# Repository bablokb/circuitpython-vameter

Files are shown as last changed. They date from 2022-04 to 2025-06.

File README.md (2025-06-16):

Project circuitpython-vameter
=============================

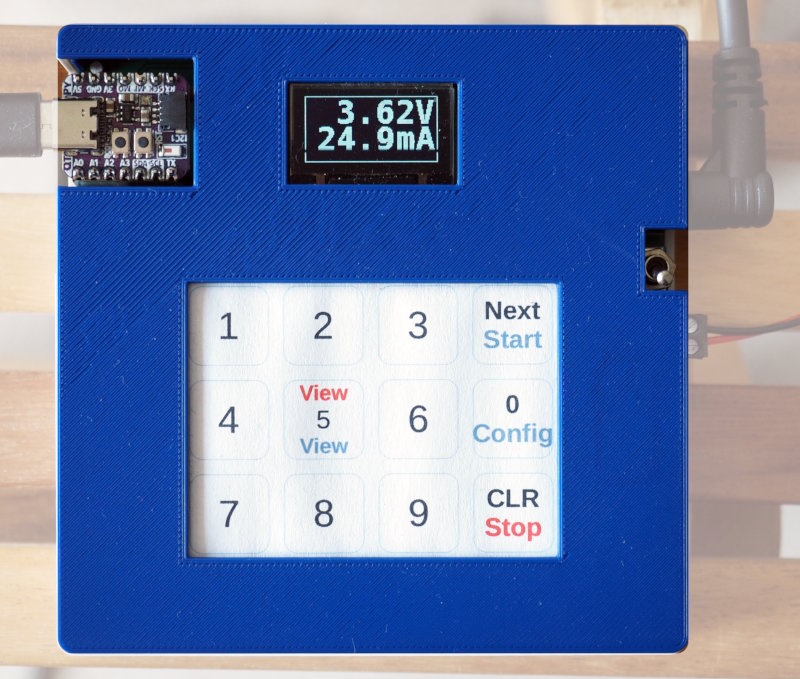
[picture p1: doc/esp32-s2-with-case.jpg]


News
----

  - 06/2025: added support for INA3221.<br>
    Changed configuration-setup (incompatible, see below)<br>
    Changed support for ESP-01S (see [ESP-01S logging HowTo](doc/esp01logger.md))
  - 02/2025: added support for recording gpio-state during sampling
  - 01/2025: added support for DataProvider-specific configuration screens
  - 02/2024: added support for logging to SD-card
  - 10/2023: added support for INA260

Overview
--------

This repository contains the necessary CircuitPyhon software to drive a
voltage/current meter based on the following components:

  - INA3221 current-sensor breakout or
  - INA219 current-sensor breakout or
  - INA260 current-sensor breakout
  - Mini OLED display with 128x64 (based on a SSD1306-chip) or
  - SPI TFT-1.8" display (based on a ST7735R-chip)
  - 4x3 touchpad (based on a MPR121-chip)

Measurements are shown on the display and written as CSV to the
console.

Note that the display and touchpad are not strictly necessary. In
this case (i.e. you only want to measure voltage/current)
you have to change configuration values directly within the source-code.

If you want to use other components (especially a bigger display or
knobs and buttons instead of the touchpad) you should read the
[hacking guide](doc/hacking.md).

Also the main program is agnostic about which kind of sensor is
sampled. Just by providing a data-provider class you can collect data of any
sensor. This is also documented in the [hacking guide](doc/hacking.md).

Hardware
--------

All components use I2C except if you choose to use the SPI-display.
Connect the respective SDA, SCL, Vcc and GND
pins with the relevant pins of the MCU. Don't forget pullups, the builtin
pullups of the MCU are usually too weak.

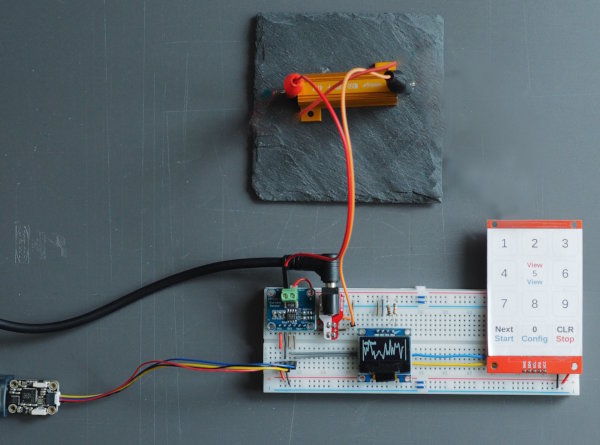
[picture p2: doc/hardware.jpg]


On the left edge: the MCU, a RP2040-Qt-Trinkey. The INA219 is left to the
barrel-jack on the upper-left side of the breadboard. On the top edge
of the image is a load-resistor. In real applications this resistor is
replaced by the load you want to measure.

The mini-oled with 128x64 pixels is in the middle, on the right is a
MPR121-based keypad with 12 keys. A template for the key-mapping is in
`doc/keypad-template.png` and `doc/keypad-template.odg`.
The latter also has a version for horizontal orientation.

The INA219-breakout has two pins (next to the I2C-interface) and a
screw-terminal for attachement of the power-source (V+) and the load (V-).
**Don't use the pins, use the screw-terminal** or else your results will
be off by about 20%.

The INA260 offers a larger measurment-range than the INA219 (up to 36V/15A
compared to 32V/2A), but is more expensive and the resolution is a
tad worse. See the relevant tutorials and datasheets for details.

The INA3221 is a three-channel chip and measures up to 26V/3.2A with a
resolution of 0.4mA.

Installation (Pico or other MCU)
--------------------------------

Steps:

  0. Install the current version of CircuitPython to your device

  1. Install the following libraries from the CircuitPython library-bundle to
     the `lib`-directory of your device  

       - adafruit_bitmap_font
       - adafruit_bus_device
       - adafruit_connection_manager
       - adafruit_display_shapes
       - adafruit_display_text
       - adafruit_displayio_ssd1306
       - adafruit_ina219
       - adafruit_ina260
       - adafruit_ina3221
       - adafruit_mpr121
       - adafruit_register
       - adafruit_requests
       - adafruit_st7735r
       - adafruit_ticks
       - asyncio

     The preferred way to do this is to use `circup` (note that the device
     must be mounted):  

         sudo apt-get -y install pip3
         sudo pip3 install circup
         circup --path /mountpoint/of/device install -r requirements.txt

  2. Clone the repository

  3. Configure the software for your board and preferences. See
     [Configuration](#configuration) below.

  4. Check `src/lib/INA219DataProvider.py` for the correct voltage range.
     The code uses the library-default of 32V/2A, but this can be changed
     to 16V/1A or 16V/400mA. The additional precision is probably not
     worth the effort. Also, you can change the chip-internal oversampling
     of the ADC. The Default uses 8x oversampling resulting in a minimal
     sampling time of 4.26ms. Defaults for the INA260 are in
     `src/lib/INA260DataProvider.py`

  5. Copy all files from below `src` to your device.

Installation (Raspberry Pi)
---------------------------

There is a native build of CircuitPython for the Raspberry Pi, but that
build is extremely slow and not usable yet. The better option is to
use _Blinka_, an emulation layer which provides classes and methods usually
missing in a native python installation. Blinka runs on various SBCs,
the Raspberry Pi is only the most prominent example.

You can install the project on a Raspberry Pi (or any other Debian-based SBC
with Blinka-support) using:

    sudo tools/install-pi

This installs the project files, Blinka and all necessary libraries to
`/usr/local/cp-vameter`. To run the program, just use the command
`cp-vameter`. This assumes that `/usr/local/bin` is within your path.

Note that the installation is quite slow, because the install-command
installs everything to a python-virtenv. Especially download, compile
and install of numpy takes a lot of time, even on the faster Pis. For
running the program, a Pi-Zero is more than sufficient.

Also note that Blinka currently only supports SPI-displays with 16-bit
colors.

Configuration
-------------

Configuration is done using variables from three different files:

  - `src/<board_id>/board_config.py`: board-specific pins
  - `src/def_config.py`: default values
  - `src/user_config.py`: user-specific overrides

A board-specific configuration file is usually not necessary. There
are some seldom cases where the board uses different names for some
pins (e.g. `board.SCLK` instead of `board.SCK`). In this case a
board-specifc file is necessary. Other cases could be boards with
hard-wired displays/SD-slots that use specific pins for these
peripherals.

This repository has support-files for a number of platforms. If you use
a different MCU and that MCU does not provide the default pins, you should
create a directory `src/<board_id>` with a file `board_config.py`. Please
also create a pull-request in this case. `<board_id>` is the value
of `board.board_id` which you can query in the REPL after importing
the board-module.

The user-specific configuration file `src/user_config.py` is not part
of the repository. Copy `src/def_config.py` and keep only variables
you actually change.

**Note: starting with version 04/2025, the format of the configuration
file has changed.** Be sure to update any exiting user-specific
configuration files to match the format of `src/def_config.py`.

Usage
-----

The program is in three modes: _ready_ (after power-on and reset),
_active_ and _config_. Possible transitions are _ready-active-ready_ and
_ready-config-ready_.

If no keypad is detected, the program runs exactly once using the
defaults defined in the configuration files.

To switch modes, use the keypad:

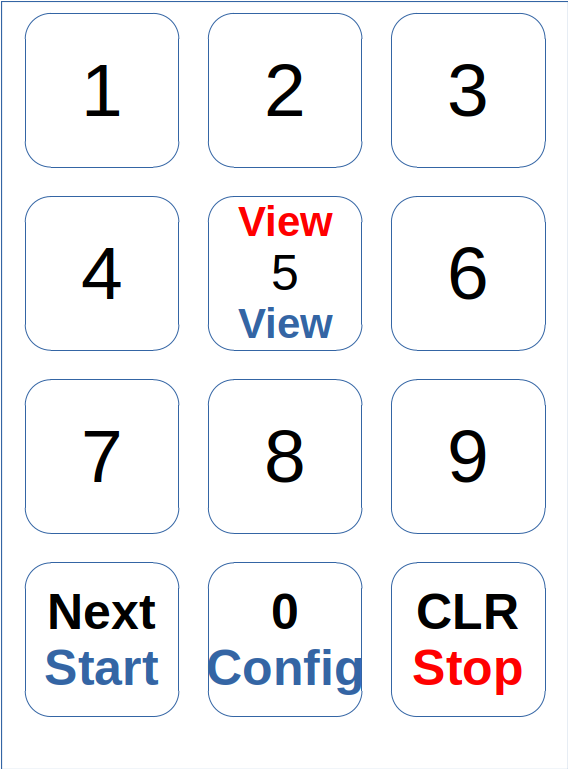
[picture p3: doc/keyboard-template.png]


Keys in blue are valid for the ready-mode, keys in black during configuration
and keys in red during the active-mode.

If you run the program on a SBC using the Blinka-emulation, you can
also provide settings via commandline parameters. For a list of options
run

    cp-vameter -h

This is especially useful for headless operation, i.e. without display
and without keypad.

Ready-Mode
----------

The ready-mode displays the last measurement-results (switch by using the
"View"-button):

 

Use the "Start" or "Config"-buttons to start a measurement or to enter
configuration mode.

Config-Mode
-----------

Once the program is in configuration mode, you can enter various parameters:

  - **Int-Scale**: the scale of the sampling interval in ms/s/m/h/d  
    The values 1-5 on the keypad are mapped to these intervals
  - **Interval**: the sampling interval in the given scale  
    
  - **Duration**: the duration of the measurement. A value of zero
    will run the measurement until it is explicitly or implicitly stopped.
    The scale of the duration depends on the scale of the interval. E.g. a
    interval-scale of 'ms' (i.e. in milliseconds) will force a duration
    measured in seconds. For an interval-scale of 's' the duration-scale will
    be in minutes and so on.  
    
  - **Update**: update-interval of the screen in milliseconds. These updates
    slow down the sampling, so make sure this value is much larger than the
    value of `interval`. Setting the value to zero will disable
    updates of the display during measurement.  
    
  - **DataProvider specific Configuration**: additional configurations for
    the DataProvider in use.

The "Next"-button will navigate through the configuration screens, after the
last item the system switches back to ready-mode.

DataProvider specific configuration is available for:

  - [`INA219Dataprovider`](./doc/ina219-config.md)
  - [`INA260Dataprovider`](./doc/ina260-config.md)

Active-Mode
-----------

During active-mode the program continuously reads the sensor and collects
and displays data. Actual sampling starts as soon as the voltage and
current is above a default threshold (1V/0.5mA) and stops again once

  - the values drop again below these limits, or
  - the configured measurement duration is reached or
  - you press the "Stop"-button

Using the "View"-button you cycle through various views:

  - voltage and current  
    
  - elapsed time  
    
  - plot-view of voltage  
    
  - plot-view of current  
    

Recording State during Sampling
-------------------------------

To record application state during sampling, you need extra pins
that the application sets to high or low depending on the state. These
pins have to be connected to the driving MUC and should be operated in
push-pull mode by the device under test.

In addition, you need to set e.g.

    PINS_APP = [(board.GPx,1), (board.GPy,0)]

in your `src/user_config.py`. `board.GPx` and `board.GPy` are gpios of
the MCU running circuitpython-vameter, not the gpios of the device under
test.

The example uses one state-pins that is active high and a second that is
active low.

Tips and Tricks
---------------

The default configuration of the sensor uses 8x oversampling for the
internal ADC. This reduces noise. Sampling-time according to the
datasheet is 4.26ms. Using less oversampling or less precision you
can bring this down to below 1ms, but if you really need high-frequency
sampling in this range you should think about reimplementing the project
using an optimzed setup and probably C/C++.

Using a Pico, you can reach a minimal sampling interval of about 9.5ms
(about 5.4ms measured on a Pi3B+, about 6.6ms on a QT Py ESP32-S2).

Display-updates take about 330ms. During update, you loose all samples.
*Setting the update-interval to zero prevents data-loss*, but you
can't see the values during measurement. When the
sampling-interval is larger than 330ms, no data-loss occurs regardless
of display-updates.

During active measurement, the default setup not only displays the
values, but also plots of the data. This is also costly (in speed
and memory) and can be disabled in `src/user_config.py` with the constant
`DEF_PLOTS`.

Note that the plots _don't_ show all measured values, but only the values
during display-updates. I.e. the plots just show the values from the
normal value-view across time. If you sample at 100ms and the display
update is every second, you will see every tenth value.

For ex-post data-visualization, save the data from the serial output
to a file and then use the
[Python Datamonitor](https://github.com/bablokb/py-datamon) to create
a plot. A ready to use configuration-file is in
[doc/cp-vameter.json](./cp-vameter.json).

The INA219 provides voltage, current and power. The default configuration
does not sample power. If you need all three values, you can change
this within `lib/INA219DataProvider` (set `WITH_POWER=True`).

In this file you can also change some additional settings, e.g. sample
frequency and voltage/current range as well as the cutoff-values used
for detecting start and stop of measurements.

Logging via WLAN is possible either with native WIFI (for those boards
with builtin WIFI) or an additional ESP-01S MCU connected to the UART
of the device. For details, read the [ESP-01S logging
HowTo](doc/esp01logger.md).

If the program runs on an device with native WIFI you can use the
builtin wifi for data-logging. See [UDP logging
HowTo](doc/udplogger.md) for details.

You can also log to a file on a SD-card. Add the following line to
your `user_config.py`:

    from SDCardLogger import DataLogger

This is useful for autonomous long-term logging, e.g. when charging a
battery. Tested with a Qt-Py-RP2040 with SD-card BFF. Fastest logging
interval was 7ms.

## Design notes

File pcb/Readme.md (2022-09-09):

A PCB for the INA219 and INA260
===============================

In this directory you will find the KiCAD-files for a 10x10cm pcb
for the INA219 and the INA260. The latter is untested, since it
is currently not available. The pcb is symetrical, i.e. you either
add components for the INA219 (top-left, top and middle right) or
for the INA260.

The connectors on the top and bottom are for the OLED and the keypad.
Alternatively, you could add Grove-connectors.
You also have to solder the two pullup-resistors in the middle.

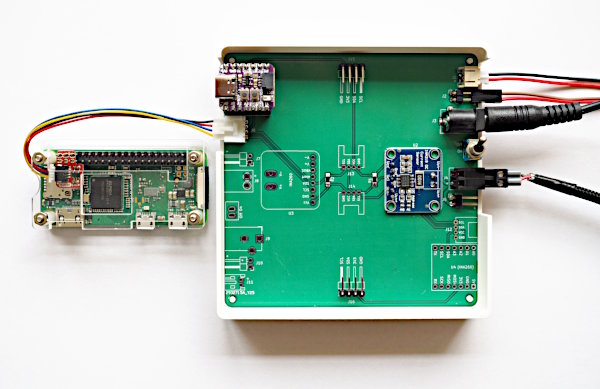
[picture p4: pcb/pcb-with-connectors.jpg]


The image shows a pcb with INA219. On the left you _either_ connect
a suitable mcu (see below) on the top-left, _or_ you connect an external
mcu (or Pi) using an I2C-Grove-connector. In the image you can see
both options.

On the right side, you have three power inputs for the load (use only one):

  - a JST-PH2 connector for LiPos
  - DuPont jumper pins
  - a 5.5/2.1mm barrel jack

Below the power switch are two power connectors (connect one of them to
to the load):

  - an AKL-182 socket
  - DuPont jumper pins

The AKL-182 socket takes AKL-169 plugs. I use these with various adapter
wires, equiped e.g. with micro-USB, USB-C, JST-PH2 on the other end.

As an alternative, you could use plain 3.5mm screw-terminals.

The pcb was ordered using JLCPCB.

OpenSCAD-files for the case are available in the toplevel `3D`-directory.

Supported MCUs
--------------

The driving MCU can be added to the board if it uses the XIAO-standard.
Possible alternatives:

  - Adafruit QT Py RP2400
  - Adafruit QT Py ESP32-S2
  - Seeedstudio XIAO RP2400

The form-factor alone is not sufficient, the MCU must also have enough
RAM/flash to support the application.

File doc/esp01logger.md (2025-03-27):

Howto use the ESP01Datalogger
=============================

Support for the ESP-01S has been dropped. The code used the library
`adafruit_espat` which is no longer supported.

Nevertheless, logging with WIFI using an ESP-01S still works. To use
it, you need to install the library
[circuitpython-esp32at](https://github.com/bablokb/circuit-python-esp32at). Once
installed, initialize the wifi-coprocessor in your `user_config.py`. After
initialization, use the standard [UDPLogger](./udplogger.md) for
logging.

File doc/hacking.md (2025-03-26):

Porting to other hardware
=========================

Since CircuitPython runs on a wide array of platforms, this is not so
much about porting the code to something totally different, but to adapt
it for other hardware components.

This document gives an overview over the application classes to help
changing the code for other hardware. All files are relative to `src`, after
installation relative to the root of the device.

main.py
-------

The main application-file. It imports classes for specific features.
When implementing new versions for features (e.g. data-provider, logging),
keep the class name and change the import statement. The files
`lib/FakeDataProvider.py` vs. `lib/INA219DataProvider.py` are an example:
both files define the class `DataProvider`.

lib/View.py
-----------

This file defines all the views for the application. To adapt to larger
displays, add colors and so on you have to provide your own implementation.

The small 128x64 display is fine for up to three rows of data. The plot-view
is already more of a gimmick. Better, but still afordable are
160x128 TFT-displays (attached to SPI). The current support of this
display is minimal, the code only uses the central 128x64 pixels and
ignores the availability of colors.

The fonts in the `fonts`-directory are stripped down versions of the
original fonts. If you need additional characters, follow the instructions
in [fonts.md](./fonts.md).

lib/Touchpad.py
---------------

This file implements the class `KeyEventProvider`. For other hardware like
buttons and rotary-encoders, implement a class with identical methods.

An interessting platform would be the PyPortal-line. It has an integrated
processor and with the touch-display you could implement an onscreen
touchpad.

lib/INA219DataProvider.py
-------------------------

The file implements the class `DataProvider`. You could swap the dataprovider
with something simlar (e.g. INA260) or totally different. A BME280 sensor with
temperature, pressure and humidity would be a candidate.

An alternative implementation which is part of the project is the
`FakeDataProvider.py`. It is useful during development and testing since it
neither needs a real current-sensor, nor an existing load.

Other sensors would certainly need other characters within the font-set,
so you must also update the fonts.

If the data-provider is not targeted at sampling in the milliseconds realm,
you should also change the constant `DEF_TM_SCALE` to `s` instead of `ms` in
`src/user_config.py`.

lib/SerialLogger.py
-------------------

Implements the class `DataLogger` (logging to the serial console).
Alternative implementations must implement at least the `log()`-method.

lib/UDPLogger.py
------------------

Implements the class `DataLogger` (logging via WLAN). For details, read
the [UDP logging HowTo](./udplogger.md).

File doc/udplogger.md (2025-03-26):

Howto use the UDPLogger
=======================

Overview
--------

This class allows data-logging via WLAN on devices with native WIFI.
This is not for devices that have an ESP32 as a coprocessor, e.g. a
PyPortal!

UDP works even if no remote host is listening and thus more robust
than TCP. The setup time (connection to AP) is quite long, but the
overhead during logging is only about 1ms.

To receive the data, run something like

    netcat -u l 6500

on a machine in the network and pass the ip and port of the machine in
the file `secrets.py` (see below).

As an alternative, run

    tools/cp-datalogger.py -t -o mydata.csv

The complete list of options for `cp-datalogger.py` are available via

    tools/cp-datalogger.py -h

Configuration
-------------

Add

    from UDPLogger import DataLogger

to your `user_config.py`.

secrets.py
----------

Create the file `secrets.py` with the following content:

    secrets = {
      'ssid' :        'ssid-of-accesss-point',
      'password' :    'PSK-2 shared key',
      'retry':        number-of-retries,
      'remote_ip':    'IP of remote host receiving the logs',
      'remote_port' : port-number
    }

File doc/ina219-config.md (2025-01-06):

Specific Configuration for the INA219
=====================================

The INA219 dataprovider allows the configuration of the measurement range
and the ADC-oversampling.

Measurement Range
-----------------

Available configuration options (default value: **1**):

  - **2**: 32V, 2A with 0.49mA resolution
  - **1**: 32V, 1A with 0.25mA resolution
  - **400**: 16V, 400mA with 0.01mA resolution

ADC Oversampling
----------------

Oversampling is related to noise and conversion time. A higher oversampling
will result in less noise but with a higher conversion time.

Available configuration options (default value: **6**):

  - **0**:   9 bit,    1 sample,     84us
  - **1**:  10 bit,    1 sample,    148us
  - **2**:  11 bit,    1 sample,    276us
  - **3**:  12 bit,    1 sample,    532us
  - **4**:  12 bit,    2 samples,  1.06ms
  - **5**:  12 bit,    4 samples,  2.13ms
  - **6**:  12 bit,    8 samples,  4.26ms
  - **7**:  12 bit,   16 samples,  8.51ms
  - **8**:  12 bit,   32 samples, 17.02ms
  - **9**:  12 bit,   64 samples, 34.05ms
  - **10**: 12 bit,  128 samples, 68.10ms

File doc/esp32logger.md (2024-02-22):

Howto use the ESP32Datalogger
=============================

Overview
--------

This class allows data-logging via WLAN on devices with the ESP32-chip
(e.g. Qt Py ESP32-S2 from Adafruit). This is not for devices that
have an ESP32 as a coprocessor, e.g. a PyPortal!

Compared to the ESP-01, the setup time (connection to AP) is quite long,
but the overhead during logging is only about 1ms.

To receive the data, run something like

    netcat -u l 6500

on a machine in the network and pass the ip and port of the machine in
the file `secrets.py` (see below).

As an alternative, run

    tools/cp-datalogger.py -t -o mydata.csv

The complete list of options for `cp-datalogger.py` are available via

    tools/cp-datalogger.py -h

Configuration
-------------

Add

    from ESP32DataLogger import DataLogger

to your `user_config.py`.

secrets.py
----------

Create the file `secrets.py` with the following content:

    secrets = {
      'ssid' :        'ssid-of-accesss-point',
      'password' :    'PSK-2 shared key',
      'transport':    'UDP or TCP',
      'retry':        number-of-retries,
      'remote_ip':    'IP of remote host receiving the logs',
      'remote_port' : port-number
    }

UDP works even if no remote host is listening and is a bit faster.

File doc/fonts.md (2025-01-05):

Fonts
=====

The program uses the *DejaVuSansMono-Bold* font in two different
font-sizes. The tiny-font is the default builtin font `terminalio.FONT`. If
you prefer a different tiny-font, change the definition within
'src/lib/View.py`.

To keep the size small, only the subset of characters actually used
are within the fonts. These subsets were created following the
tutorial from
<https://learn.adafruit.com/custom-fonts-for-pyportal-circuitpython-display>.

Conversion to PCF was done using the online converter from
<https://adafruit.github.io/web-bdftopcf/>.

Text strings
------------

The program uses the following text strings:

  - Int-Scale:
  - Interval:
  - Oversample:
  - Duration:
  - Update:
  - min:
  - mean:
  - max:
  - Calibration:
  - ADC-Overs.:
  - AVG-Count:
  - Conv-Time:

Values and Units
----------------

Characters needed for values and units:

  - numbers
  - V
  - mA
  - mW
  - ms, s, m, h, d

Character table
---------------

Note that the tiny-version if the font currently contains all characters
unless you change the definition. In this case ensure that all characters
from the table are contained in the font.

| Char | Tiny | Small | Large |
|---|---|---|---|
| sp | X  | X | X |
| . | X  | X | X |
| - | | X | X |
| 0 | X  | X | X |
| 1 | X  | X | X |
| 2 | X  | X | X |
| 3 | X  | X | X |
| 4 | X  | X | X |
| 5 | X  | X | X |
| 6 | X  | X | X |
| 7 | X  | X | X |
| 8 | X  | X | X |
| 9 | X  | X | X |
| : | X  | X | X |
| A | X  | X | X |
| C | | X | |
| D | | X | |
| G | | X | |
| I | | X | |
| M | X  | X | X |
| O | | X | |
| S | | X | |
| U | | X | |
| V | X  | X | X |
| W | X  | X | |
| a | | X | |
| b | | X | |
| c | | X | |
| d | | X | X |
| e | | X | |
| h | | X | X |
| i | | X | |
| l | | X | |
| m | X  | X | X |
| n | | X | |
| o | | X | |
| p | | X | |
| r | | X | |
| s | X  | X | X |
| t | | X | |
| u | | X | |
| v | | X | |
| x | | X | |
|------|------|-------|-------|

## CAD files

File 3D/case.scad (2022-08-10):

// -----------------------------------------------------------------------------
// 3D-Model (OpenSCAD) case (bottom) for INA219-pcb.
//
// Author: Bernhard Bablok
// License: GPL3
//
// ---------------------------------------------------------------------------

include <dimensions.scad>
include <BOSL2/std.scad>


// --- pcb-support   ---------------------------------------------------------

module pcb_support() {
  h = z_sup;
  d = 2*r_pcb;
  z = b-fuzz;
  move([r_pcb+w4+gap,r_pcb+w4+gap,z]) cyl(h=h,d=d,anchor=BOTTOM+CENTER);
  move([r_pcb+w4+gap,y_pcb-r_pcb+w4,z]) cyl(h=h,d=d,anchor=BOTTOM+CENTER);
  move([x_pcb-r_pcb+w4,r_pcb+w4+gap,z]) cyl(h=h,d=d,anchor=BOTTOM+CENTER);
  move([x_pcb-r_pcb+w4,y_pcb-r_pcb+w4,z]) cyl(h=h,d=d,anchor=BOTTOM+CENTER);
}


// --- pcb-holder (fits to mounting holes)   ---------------------------------

module pcb_holder() {
  h = 2*z_pcb;
  d = d_sup - gap;
  z = b + z_sup-2*fuzz;
  move([r_pcb+w4+gap,r_pcb+w4+gap,z]) cyl(h=h,d=d,anchor=BOTTOM+CENTER);
  move([r_pcb+w4+gap,y_pcb-r_pcb+w4,z]) cyl(h=h,d=d,anchor=BOTTOM+CENTER);
  move([x_pcb-r_pcb+w4,r_pcb+w4+gap,z]) cyl(h=h,d=d,anchor=BOTTOM+CENTER);
  move([x_pcb-r_pcb+w4,y_pcb-r_pcb+w4,z]) cyl(h=h,d=d,anchor=BOTTOM+CENTER);
}

// --- connector for cover-snap   --------------------------------------------

module snap_male(orient) {
  prismoid(size1=[2*snap_h,snap_w], size2=[0,snap_w-2*snap_h], 
           h=snap_h, orient=orient, anchor=FRONT+RIGHT+BOTTOM
  );
}


// --- case (bottom-part)   --------------------------------------------------

module case() {
  z = b + z_sup + z_pcb + zsize;
  difference() {
    cuboid(                                          // outer
      [xsize+2*w4,ysize+2*w4,z], rounding=r_pcb,
      edges="Z",
      anchor=FRONT+LEFT+BOTTOM
    );
    cuboid(                                          // minus inner
      [xsize,ysize,z], rounding=r_pcb,
      edges="Z", p1=[w4,w4,b],
      anchor=FRONT+LEFT+BOTTOM
    );

    cuboid([x_mcu_grove,w4+2*fuzz,z],
      p1=[w4+gap+x_mcu_off,0,b+z_sup+z_pcb]);               // cutout mcu/grove
    cuboid([x_conn,w4+2*fuzz,z],
      p1=[w4+gap+x_conn_off,ysize+w4-fuzz,b+z_sup+z_pcb]);  // cutout connectors
  }

  pcb_support();
  pcb_holder();
}

// --- top-level object   ----------------------------------------------------

case();

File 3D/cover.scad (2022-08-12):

// -----------------------------------------------------------------------------
// 3D-Model (OpenSCAD) cover (top) for INA219-pcb.
//
// Author: Bernhard Bablok
// License: GPL3
//
// -----------------------------------------------------------------------------

include <dimensions.scad>
include <mpr121-keypad.scad>
include <oled-128x64.scad>

include <BOSL2/std.scad>


x      = xsize+2*w4;
y      = ysize+2*w4;
xr_mcu = w4+gap+x_mcu_off+x_mcu;         // right border of x_mcu

y_kp = (y-yi_kp)/2 -                     // (total size - cutout keypad size)/2 minus
       (yo_kp - yi_kp - yi_kp_off);      // lower offset of cutout keypad

module cover() {
  difference() {
    cuboid(
        [x,y,b], rounding=3,
        edges="Z", p1=[0,0,0],
        anchor=FRONT+LEFT+BOTTOM
    );
    cuboid([x_mcu,y_mcu,b+2*fuzz],p1=[w4+gap+x_mcu_off,-fuzz,-fuzz]);      // cutout for mcu
    cuboid([x_sw,y_sw,b+2*fuzz],p1=[w4+gap+x_sw_off,y-y_sw+fuzz,-fuzz]);   // cutout for switch
    cuboid([y_oled,x_oled,b+2*fuzz],p1=[w4+gap+x_mcu_off,
                                      (y-x_oled)/2,-fuzz]);                // empty space for oled
    cuboid([xo_kp,yo_kp,b+2*fuzz],p1=[xr_mcu + (x-xr_mcu-xo_kp)/2,
                                      y_kp,-fuzz]);                        // empty space for keypad
    }
  // add oled
  move([y_oled+w4+gap+x_mcu_off,(y-x_oled)/2,b]) zrot(90) zflip() oled();

  // add keypad
  move([xr_mcu + (x-xr_mcu-xo_kp)/2,y_kp,b]) mirror([0,0,1]) yflip(y=yo_kp/2) keypad_frame();
}

module wall() {
  z = zsize - 1;
  difference() {
    cuboid([xsize-gap,ysize-gap,z], rounding=3, edges="Z",
           anchor=FRONT+LEFT+TOP,p1=[w4+gap/2,w4+gap/2,-z]);
    cuboid([xsize-gap-2*w2,ysize-gap-2*w2,z+2*fuzz], rounding=3, edges="Z",
            anchor=FRONT+LEFT+TOP,p1=[w4+gap/2+w2,w4+gap/2+w2,-z]);
    cuboid([x_mcu_grove,w4+w2+gap+fuzz,b+z+2*fuzz],
            anchor=TOP+CENTER,
            p1=[w4+gap+x_mcu_off,-fuzz,-z-b]);         // cutout for mcu+grove
    cuboid([x_conn,w4+w2+gap+fuzz,b+z+2*fuzz],
            anchor=TOP+CENTER,
            p1=[w4+gap+x_conn_off,ysize-fuzz,-z-b]);   // cutout for connectors

  }
}
cover();
wall();

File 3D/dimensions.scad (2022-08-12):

// -----------------------------------------------------------------------------
// 3D-Model (OpenSCAD) cover for INA219-pcb.
//
// Author: Bernhard Bablok
// License: GPL3
//
// -----------------------------------------------------------------------------

$fa = 1;
$fs = 0.4;
$fn = 48;

fuzz = 0.01;
w2 = 0.86;                 // 2 walls Prusa3D
w4 = 1.67;                 // 4 walls Prusa3D
gap = 0.2;                 // gap pcb to case

x_pcb = 100;               // pcb-dimensions
y_pcb = 100;
z_pcb = 1.6;
r_pcb = 3.0;               // corner radius

z_sup = 3;                 // hight of pcb-support
d_sup = 2.5;               // diameter mounting-hole

xsize = x_pcb+2*gap;       // inner size
ysize = y_pcb+2*gap;
zsize = 14;                // height above pcb 
b     = 1.4;               // base thickness

x_mcu_grove = 35;          // cutout for mcu/grove connector
x_mcu       = 21;          // cutout only muc
x_mcu_off   =  4;
y_mcu       = 22.5;

x_conn     = 59;          // cutout input/output connectors
x_conn_off =  4;

x_sw       = 10;          // cutout switch
x_sw_off   = 32;
y_sw       =  7;

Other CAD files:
3D/mpr121-keypad.scad
3D/oled-128x64.scad
3D/proto-pcb.scad

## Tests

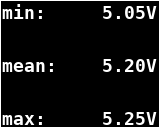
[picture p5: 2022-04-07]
doc/result-view-160x128.png

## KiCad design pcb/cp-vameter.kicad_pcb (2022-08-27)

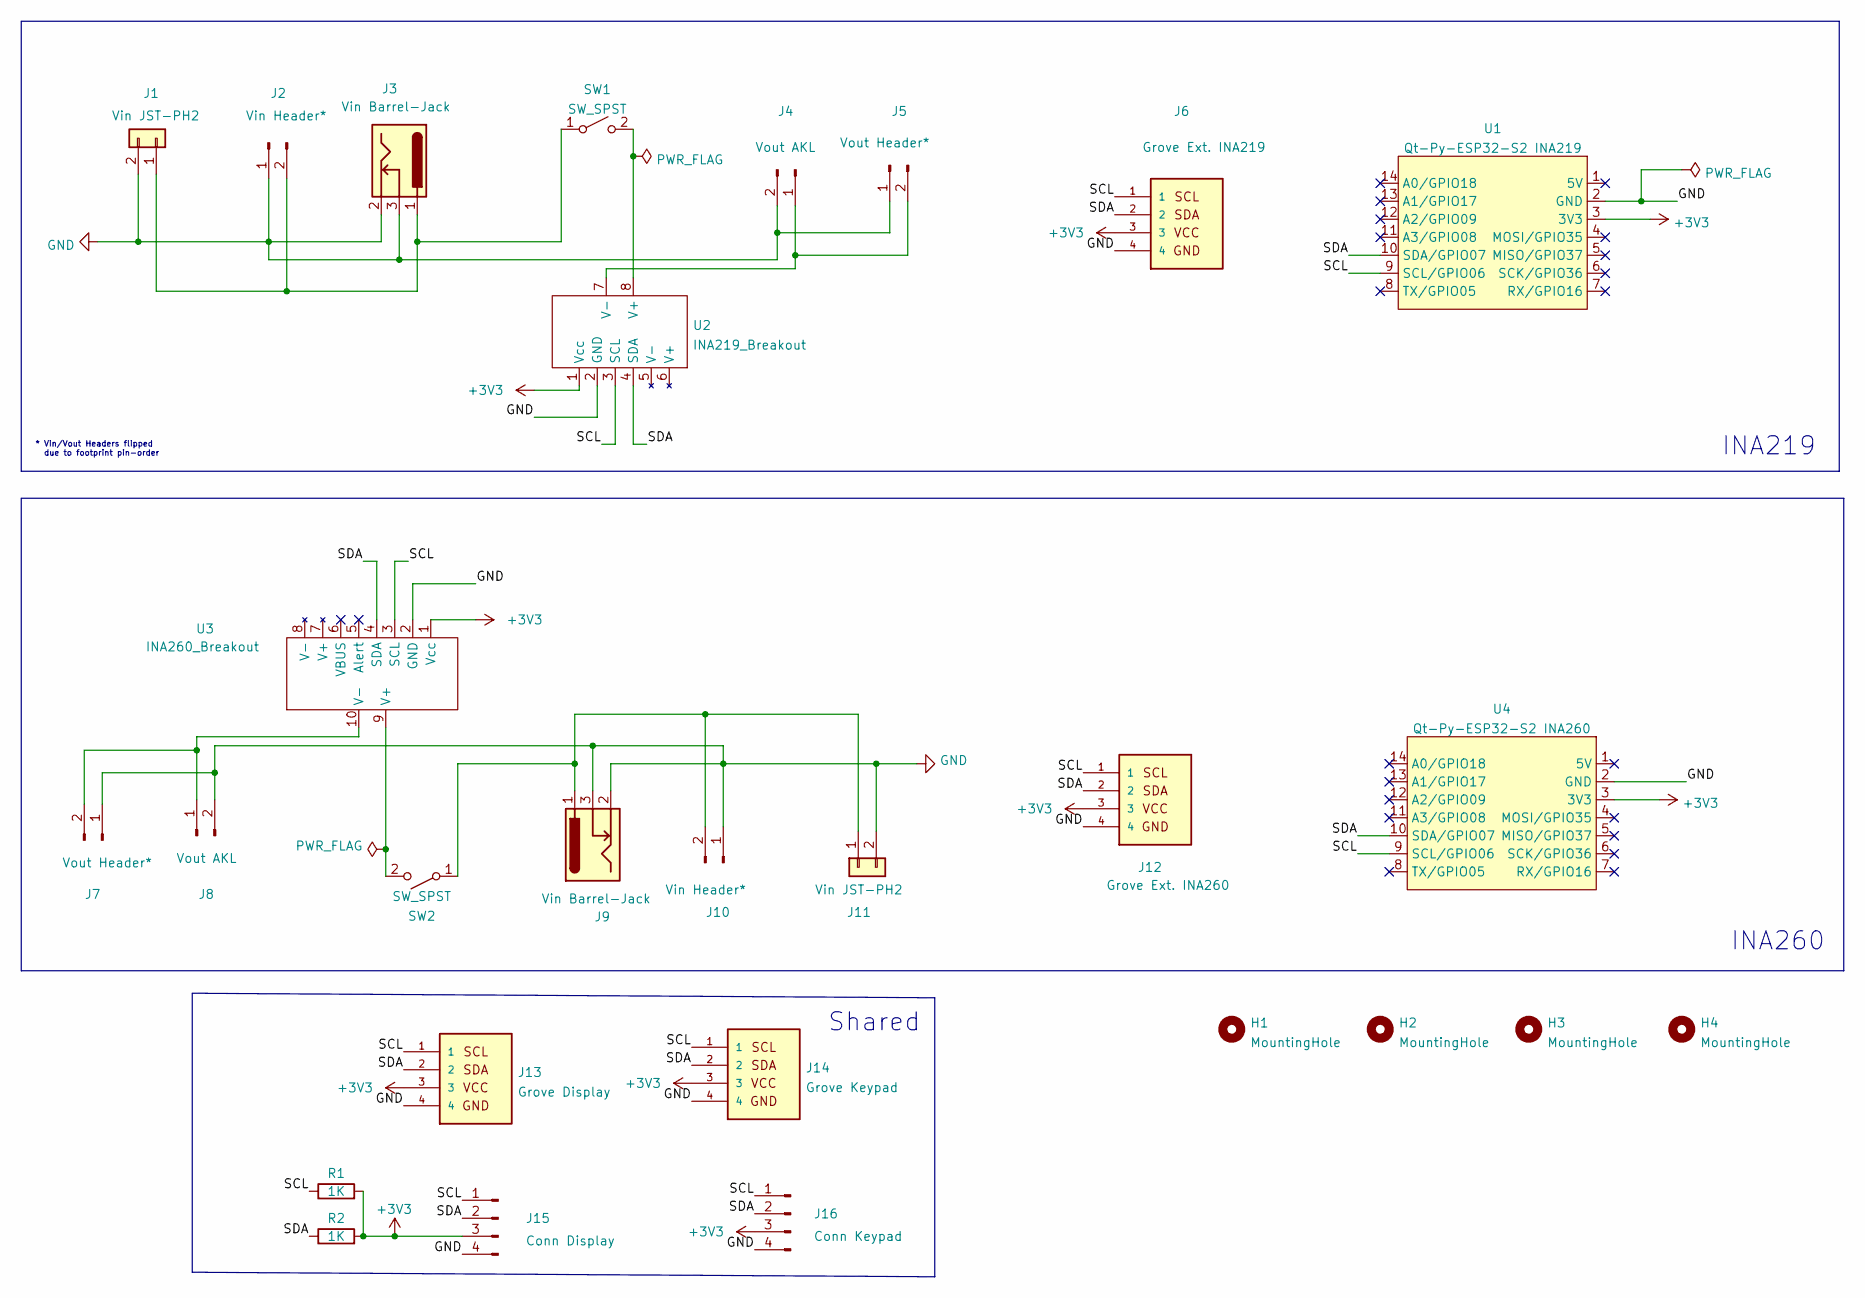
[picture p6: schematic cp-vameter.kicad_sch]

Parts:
H1, H2, H3, H4: MountingHole; MountingHole_2.5mm
J1, J11: Vin JST-PH2; JST_PH_S2B-PH-SM4-TB_1x02-1MP_P2.00mm_Horizontal
J2, J10: Vin Header*; PinHeader_1x02_P2.54mm_Horizontal
J3, J9: Vin Barrel-Jack; BarrelJack_CUI_PJ-102AH_Horizontal
J4, J8: Vout AKL; TerminalBlock_MetzConnect_Type182_PT11302HBBN_1x02_P3.50mm_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
J5, J7: Vout Header*; PinHeader_1x02_P2.54mm_Horizontal
J6: Grove Ext. INA219; grove_horizontal
J12: Grove Ext. INA260; grove_horizontal
J13: Grove Display; grove_horizontal
J14: Grove Keypad; grove_horizontal
J15: Conn Display; PinHeader_1x04_P2.54mm_Horizontal
J16: Conn Keypad; PinHeader_1x04_P2.54mm_Horizontal
R1, R2: 1K; R_1206_3216_Pad1.7x1.75mm_BB
SW1, SW2: SW_SPST; Kippschalter_On-Off
U1: Qt-Py-ESP32-S2 INA219; Qt-Py_ESP32-S2
U2: INA219_Breakout; INA219-Breakout
U3: INA260_Breakout; INA260-Breakout
U4: Qt-Py-ESP32-S2 INA260; Qt-Py_ESP32-S2

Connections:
+3V3: J6.3, J12.3, J13.3, J14.3, J15.3, J16.3, R1.2, R2.2, U1.3 (3V3), U2.1 (Vcc), U3.1 (Vcc), U4.3 (3V3)
/SCL: J6.1, J12.1, J13.1, J14.1, J15.1, J16.1, R1.1, U1.9 (SCL/GPIO06), U2.3 (SCL), U3.3 (SCL), U4.9 (SCL/GPIO06)
/SDA: J6.2, J12.2, J13.2, J14.2, J15.2, J16.2, R2.1, U1.10 (SDA/GPIO07), U2.4 (SDA), U3.4 (SDA), U4.10 (SDA/GPIO07)
GND: J1.2, J2.1, J3.2, J3.3, J4.2, J5.1, J6.4, J7.1, J8.2, J9.2, J9.3, J10.1, J11.2, J12.4, J13.4, J14.4, J15.4, J16.4, U1.2 (GND), U2.2 (GND), U3.2 (GND), U4.2 (GND)
unnamed: J1.1, J2.2, J3.1, SW1.1 (A)
unnamed: J4.1, J5.2, U2.7 (V-)
unnamed: J7.2, J8.1, U3.10 (V-)
unnamed: J9.1, J10.2, J11.1, SW2.1 (A)
unnamed: SW1.2 (B), U2.8 (V+)
unnamed: SW2.2 (B), U3.9 (V+)

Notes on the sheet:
* Vin/Vout Headers flipped due to footprint pin-order
Shared
INA260
INA219

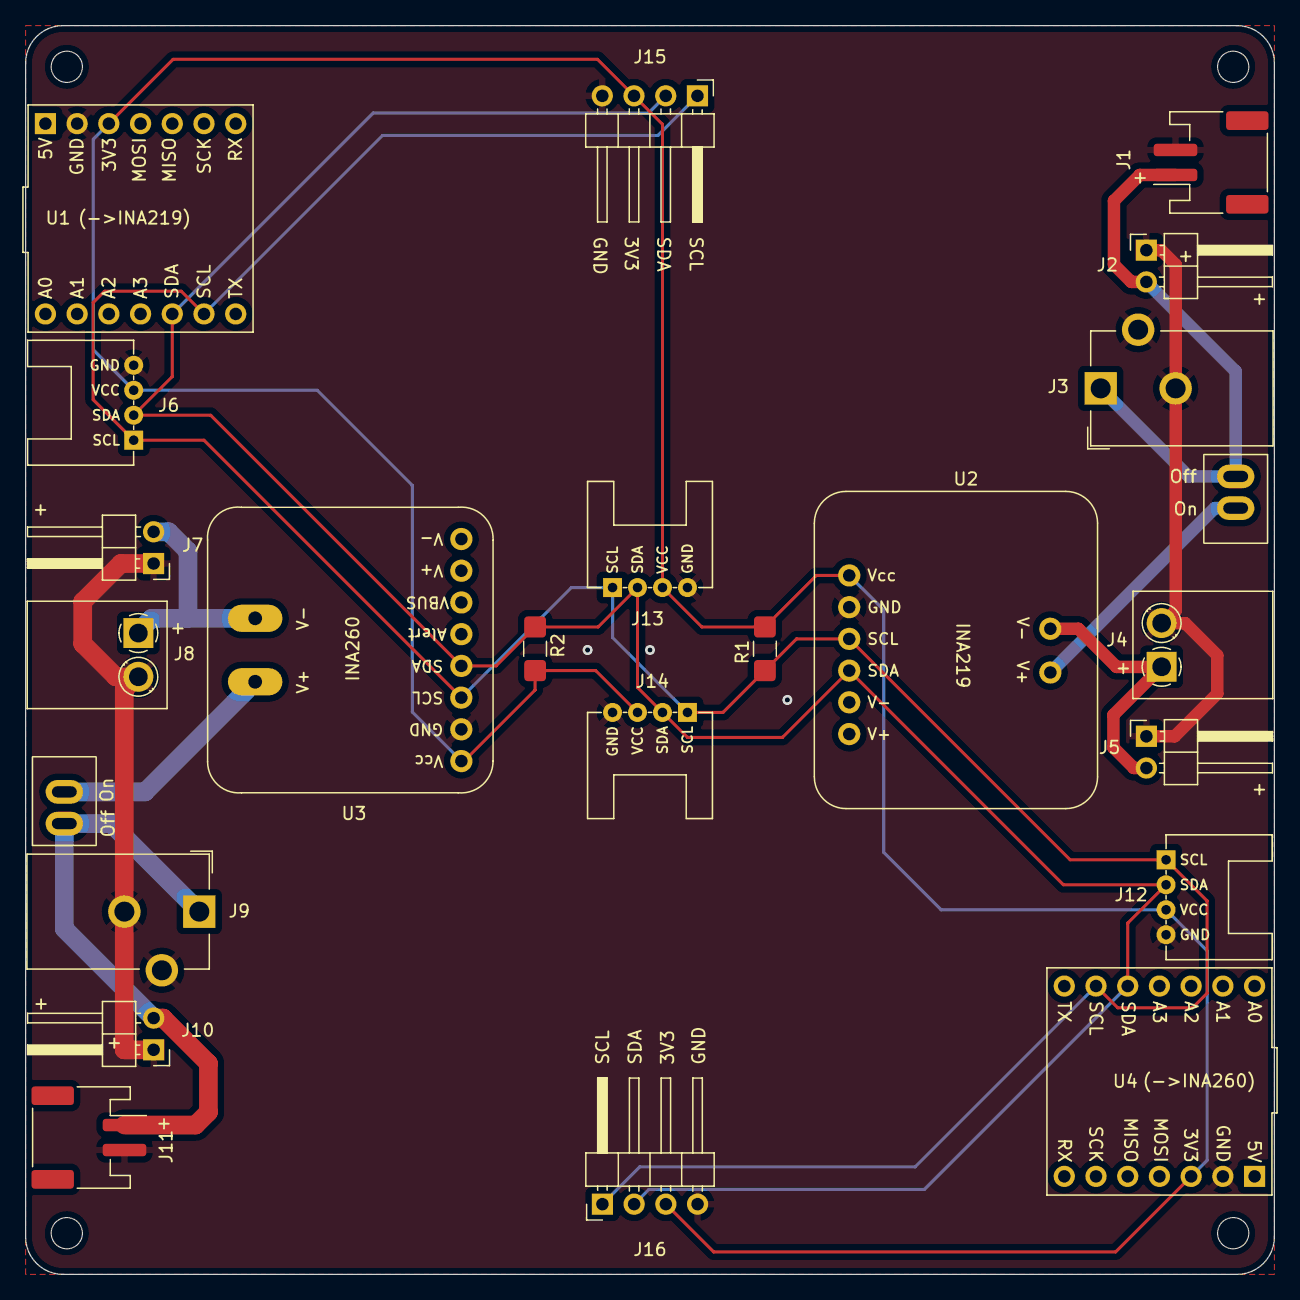
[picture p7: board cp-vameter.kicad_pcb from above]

Board: 2 copper layers, 100.0 x 100.0 mm, 28 parts (0 on the bottom side), 10 nets.

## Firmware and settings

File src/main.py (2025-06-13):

# ----------------------------------------------------------------------------
# main.py: driver program for VA-meter
#
# Author: Bernhard Bablok
# License: GPL3
#
# Website: https://github.com/bablokb/circuitpython-vameter
#
# ----------------------------------------------------------------------------

import board
import sys
import busio
import displayio
import time

import adafruit_displayio_ssd1306          # I2C-OLED display
from adafruit_st7735r import ST7735R       # SPI-TFT  display

from ReadyState  import ReadyState
from ConfigState import ConfigState
from ActiveState import ActiveState

from Touchpad           import KeyEventProvider

if hasattr(board,'__blinka__'):
  # support functions for Blinka
  import BlinkaExtensions

# --- ValueHolder class   ----------------------------------------------------

class ValueHolder:
  pass

# --- configuration   --------------------------------------------------------

from def_config import settings as def_settings

try:
  if board.board_id.startswith("RASPBERRY_PI"):
    sys.path.insert(0,"./RASPBERRY_PI")
  else:
    sys.path.insert(0,"./"+board.board_id)
  from board_config import *
except:
  print("no board-specific config-file for %s, using defaults" % board.board_id)

try:
  from user_config import settings as user_settings
except Exception as ex:
  print(f"exception in user_config: {ex}")
  print("no user-configuration found, using defaults")
  user_settings = ValueHolder()

try:
  from user_config import DataProvider
except Exception as ex:
  print(f"exception in user_config: {ex}")
  print("no user-specific data-provider, using INA219DataProvider")
  from INA219DataProvider import DataProvider

try:
  from user_config import DataLogger
except Exception as ex:
  print(f"exception in user_config: {ex}")
  print("no user-specific data-logger, using SerialLogger")
  from SerialLogger import DataLogger

# --- application class   ----------------------------------------------------

class VAMeter:
  """ application class """

  # --- constructor   --------------------------------------------------------

  def __init__(self):
    """ constructor """

    # merge default and user-settings
    self.settings = def_settings
    self._merge_settings(user_settings)
    if hasattr(board,'__blinka__'):
      # change defaults from commandline arguments
      BlinkaExtensions.update_settings(self.settings)

    # set pins from board-configuration if not already set
    g_dict = globals()
    for attr in ['pin_scl', 'pin_sda', 'pin_tx', 'pin_rx',
                 'pin_miso', 'pin_mosi', 'pin_sck',
                 'pin_sd_miso', 'pin_sd_mosi', 'pin_sd_sck', 'pin_sd_cs',
                 'pin_tft_mosi', 'pin_tft_sck', 'pin_tft_cs',
                 'pin_tft_dc', 'pin_tft_rst',
                 'pin_app'
                 ]:
      if not getattr(self.settings,attr,None):
        attr_uc = attr.upper()
        if attr_uc in g_dict:
          # already imported via board_config
          setattr(self.settings,attr,g_dict[attr_uc])
        elif hasattr(board,attr_uc[4:]):
          # use default pin-definition of board (remove leading "pin_")
          setattr(self.settings,attr,getattr(board,attr_uc[4:]))

    #self._dump_settings()

    # initialize hardware and software objects
    if not hasattr(board,'DISPLAY'):
      displayio.release_displays()

    self.i2c = busio.I2C(sda=self.settings.pin_sda,
                         scl=self.settings.pin_scl,frequency=400000)

    if self.settings.shared_spi and self.settings.pin_sck:
      self.spi = busio.SPI(clock=self.settings.pin_sck,
                           MOSI=self.settings.pin_mosi,
                           MISO=self.settings.pin_miso)
    else:
      self.spi = None

    self.data_provider  = DataProvider(self.i2c,self.settings)
    self.logger         = DataLogger(self)

    # create value-holder for results
    self.results        = ValueHolder()
    self.results.values = [[0,0,0] for i in range(self.data_provider.get_dim())]
    self.results.time   = 0
    self.results.plots  = []

    self.display = self._get_display()
    if self.display:
      self.display.auto_refresh = False

    try:
      self.key_events = KeyEventProvider(self.i2c,self.settings)
    except Exception as ex:
      print(f"warning: no KeyEventProvider: ({ex})")
      self.key_events = None

    self._ready  = ReadyState(self)
    self._active = ActiveState(self)
    if self.display:
      self._config = ConfigState(self)
    else:
      self._config = None

  # --- dump settings   ------------------------------------------------------

  def _dump_settings(self):
    """ dump settings """
    for attr in self.settings.__dict__:
      if attr[:2] == '__':
        continue
      print(f"{attr:>10}: {getattr(self.settings,attr)}")

  # --- merge generic user settings   ----------------------------------------

  def _merge_settings(self,u_settings):
    """ merge generic user settings """

    for attr in u_settings.__dict__:
      if attr[:2] == '__':
        continue
      setattr(self.settings,attr,getattr(u_settings,attr))

  # --- initialize display   -------------------------------------------------

  def _get_display(self):
    """ initialize hardware """

    if not self.settings.display:  # run headless
      return None

    if self.settings.display == 'ssd1306':
      import i2cdisplaybus
      display_bus = i2cdisplaybus.I2CDisplayBus(
        self.i2c,
        device_address=self.settings.oled_addr)
      return adafruit_displayio_ssd1306.SSD1306(
        display_bus,
        width=self.settings.oled_width,
        height=self.settings.oled_height)
    elif self.settings.display == 'st7735r':
      import fourwire
      if self.spi:
        spi = self.spi
      else:
        spi = busio.SPI(clock=self.settings.pin_tft_sck,
                        MOSI=self.settings.pin_tft_mosi)
      bus = fourwire.FourWire(spi,command=self.settings.pin_tft_dc,
                               chip_select=self.settings.pin_tft_cs,
                               reset=self.settings.pin_tft_rst)
      return ST7735R(bus,width=self.settings.tft_width,
                     height=self.settings.tft_height,
                     rotation=self.settings.tft_rotate,
                     bgr=self.settings.tft_bgr)
    elif self.settings.display == 'auto':
      if hasattr(board,'DISPLAY') and board.DISPLAY:
        return board.DISPLAY
      else:
        # try OLED display first
        try:
          import i2cdisplaybus
          display_bus = i2cdisplaybus.I2CDisplayBus(
            self.i2c, device_address=self.settings.oled_addr)
          return adafruit_displayio_ssd1306.SSD1306(
            display_bus,
            width=self.settings.oled_width,
            height=self.settings.oled_height)
        except Exception as ex:
          print(f"info: no SSD1306 in auto mode ({ex})")
          pass
        # then try SPI-display
        try:
          import fourwire
          if self.spi:
            spi = self.spi
          else:
            spi = busio.SPI(clock=self.settings.pin_tft_sck,
                            MOSI=self.settings.pin_tft_mosi)
          bus = fourwire.FourWire(spi,
                                   command=self.settings.pin_tft_dc,
                                   chip_select=self.settings.pin_tft_cs,
                                   reset=self.settings.pin_tft_rst)
          return ST7735R(bus,width=self.settings.tft_width,
                         height=self.settings.tft_height,
                         rotation=self.settings.tft_rotate,
                         bgr=self.settings.tft_bgr)
        except Exception as ex:
          print(f"info: no ST7735R in auto mode ({ex})")
          return None
    else:
      print(f"error: invalid value of settings.display: {self.settings.display}")
      return None

  # --- main loop   ----------------------------------------------------------

  def run(self):
    """ main loop """

    if not self.key_events:
      # no keypad, only one iteration without config
      self._active.run()
      self._ready.run(self._active,self._config)      # display results
    else:
      while True:
        next_state = self._ready.run(self._active,self._config)
        if next_state is None:
          break
        next_state.run()

# --- main loop   ------------------------------------------------------------

try:
  app = VAMeter()
  app.run()
except KeyboardInterrupt:
  if hasattr(board,'__blinka__'):
    # finish program without backtrace
    pass
  else:
    raise
finally:
  try:
    app.logger.close()
  except:
    pass

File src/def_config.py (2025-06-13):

# ----------------------------------------------------------------------------
# def_config.py: Default configuration-constants
#
# Don't change anything here directly, copy this file to user_config.py
# and change as necessary (delete all lines not touched)
#
# Author: Bernhard Bablok
# License: GPL3
#
# Website: https://github.com/bablokb/circuitpython-vameter
#
# ----------------------------------------------------------------------------

import board

# --- select Dataprovider (add one to user_config.py)   ----------------------

#from INA219DataProvider import DataProvider
#from INA260DataProvider import DataProvider
#from INA3221DataProvider import DataProvider

# --- select DataLogger (default is SerialLogger)   --------------------------

#from UDPLogger       import DataLogger
#from SDCardLogger    import DataLogger

# --- helper-class for settings   --------------------------------------------

class ValueHolder:
  pass

# --- settings   -------------------------------------------------------------

settings = ValueHolder()
settings.interval   = 100     # sampling-interval: 100 in the given scale
settings.int_scale  = 'ms'    # interval-scale: ms|s: ms
settings.oversample = 0       # oversampling: 0: use 1X, hide config
settings.duration   = 0       # measurement-duration: 0s (i.e. not limited)
settings.v_min      = 1.0     # threshold for V for start/stop of measurement
settings.a_min      = 0.0     # threshold for A for start/stop of measurement
settings.update     = 1000    # display update-interval: 1000ms
settings.plots      = True    # create plots
settings.exit       = False   # blinka: exit after measurement
settings.tp_orient  = 'P'     # touchpad orientation P|L
settings.display    = 'auto'  # auto|ssd1306|st7735r|None
settings.border     = 1       # draw 1px border on display

# --- pins   -----------------------------------------------------------------

# note: some pins will be set automatically from board-config if available,
#       e.g. SDA, SCL, MISO, MOSI, SCK
#
# Pins explicitely set here will override defaults from board-config

settings.pin_sda     = None
settings.pin_scl     = None

settings.pin_tx      = None
settings.pin_rx      = None

settings.shared_spi  = True  # a shared SPI-bus will use the following pins
settings.pin_miso    = None
settings.pin_mosi    = None
settings.pin_sck     = None

settings.pin_sd_miso = None  # only needed for non-shared SPI-bus
settings.pin_sd_mosi = None  # only needed for non-shared SPI-bus
settings.pin_sd_sck  = None  # only needed for non-shared SPI-bus
settings.pin_sd_cs   = None

settings.pin_tft_mosi = None  # only needed for non-shared SPI-bus
settings.pin_tft_sck  = None  # only needed for non-shared SPI-bus
settings.pin_tft_cs   = None
settings.pin_tft_dc   = None
settings.pin_tft_rst  = None

settings.pins_app    = None

# --- I2C-display   ----------------------------------------------------------

settings.oled_addr   = 0x3C
settings.oled_width  = 128
settings.oled_height = 64

# --- SPI-display   ----------------------------------------------------------

settings.tft_width  = 160
settings.tft_height = 128
settings.tft_rotate = 270
settings.tft_bgr    = True

# --- INA219-defaults   ------------------------------------------------------

settings.ina219_addr  = 0x40 # default I2C-address
settings.ina219_calib = 1    # range: 32V/1A, resolution: 244µA
settings.ina219_adc   = 6    # ADCResolution.ADCRES_12BIT_8S

# --- INA260-defaults   ------------------------------------------------------

settings.ina260_addr  = 0x40 # default I2C-address
settings.ina260_count = 16   # internal oversampling
settings.ina260_ctime = 1    # ConversionTime.TIME_204_us

# --- INA3221-defaults   -----------------------------------------------------

settings.ina3221_addr     = 0x40  # default I2C-address
settings.ina3221_channels = 111   # channel-mask: all three channels
settings.ina3221_count    = 4     # internal oversampling
settings.ina3221_ctime    = 1     # ConversionTime.TIME_204_us

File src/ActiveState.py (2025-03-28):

# ----------------------------------------------------------------------------
# ActiveState.py: Handle active-state, i.e. display current values
#
# Author: Bernhard Bablok
# License: GPL3
#
# Website: https://github.com/bablokb/circuitpython-vameter
#
# ----------------------------------------------------------------------------

import gc
import time
import sys
import asyncio
import digitalio

from Data import DataAggregator
from Scales import *

class ActiveState:
  """ manage active-state """

  # --- constructor   --------------------------------------------------------

  def __init__(self,app):
    """ constructor """

    self._app      = app
    self._settings = app.settings
    self._logger   = app.logger
    self._dim      = app.data_provider.get_dim()
    self._dios     = []

    self._stop       = False    # global stop for all tasks
    self._new_sample = False    # toggle after each sample

    if self._app.display:
      from View import ValuesView, PlotView
      self._views = [ValuesView(app.display,app.settings.border,
                                app.data_provider.get_units()),
                     ValuesView(app.display,app.settings.border,['s','s'])   # elapsed
                     ]
      if self._settings.plots:
        for unit in app.data_provider.get_units():
          plot = PlotView(app.display,app.settings.border,[unit])
          self._views.append(plot)
          app.results.plots.append(plot)

  # --- init digital IOs for state-sampling   --------------------------------

  def _init_dios(self):
    """ initialize optional state-GPIOs (read during sampling) """
    self._dios = []
    for pin,active in self._settings.pins_app:
      dio = digitalio.DigitalInOut(pin)
      dio.pull = digitalio.PULL.UP if not active else digitialio.PULL.DOWN
      self._dios.append(dio)

  # --- deinit digital IOs   -------------------------------------------------

  def _deinit_dios(self):
    """ de-initialize optional state-GPIOs """
    for dio in self._dios:
      dio.deinit()
    self._dios = []
    gc.collect()

  # --- read digital IOs   ---------------------------------------------------

  def _read_dios(self):
    """ read state of digital IOs """
    return [dio.value for dio in self._dios]

  # --- get data   -----------------------------------------------------------

  def _get_data(self):
    """ get data using oversampling """

    if self._settings.oversample < 2:
      data = self._app.data_provider.get_data()
    else:
      d_sum = [0]*self._dim
      for _ in range(self._settings.oversample):
        data = self._app.data_provider.get_data()
        for i in range(self._dim):
          d_sum[i] += data[i]
      data = [d_sum[i]/self._settings.oversample for i in range(self._dim)]
    data.extend(self._read_dios())
    return (time.monotonic(),data)

  # --- check for key-press   ------------------------------------------------

  async def _check_key(self):
    """ check for key and save it """

    if not self._app.key_events:
      return

    while not self._stop:
      key = self._app.key_events.is_key_pressed(
                                           self._app.key_events.KEYMAP_ACTIVE)
      if key == 'TOGGLE' and self._app.display:
        # switch to next view
        self._cur_view = (self._cur_view+1) % len(self._views)
      elif key == 'STOP':
        self._stop = True
        return
      await asyncio.sleep(0.1)

  # --- update views   -------------------------------------------------------

  def _update_views(self):
    """ update views """

    if self._app.display and self._settings.update:
      if self._new_sample and self._settings.plots:
        # update plots
        #s =  time.monotonic()
        for i,value in enumerate(self.data_v):
          self._views[2+i].set_values([value])
        #print("#display plots: %f" % (time.monotonic()-s))
      #s =  time.monotonic()
      if self._new_sample and self._cur_view == 0:
        # measurement values
        self._views[self._cur_view].set_values(
          self.data_v,time.monotonic()-self._start_t)
      elif self._cur_view == 1:
        # elapsed time
        self._views[self._cur_view].set_values(
          [(time.monotonic()-self._start_t)/self._dur_fac,
           self._settings.duration],-1)
      #print("#display values: %f" % (time.monotonic()-s))

  # --- show current views   -------------------------------------------------

  async def _show_view(self):
    """ show current view """

    if not (self._app.display and self._settings.update):
      return

    cur_view = self._cur_view
    update_time = 0.33                                  # pico,SSD1306
    while not self._stop:
      await asyncio.sleep(self._settings.update/1000)
      gap = self._next_sample_t - time.monotonic()

      # don't start update just before next sample, unless sampling-interval
      # is smaller than update-time (in the latter case we miss samples
      # anyhow)
      if gap < update_time and update_time < self._int_t:
        # wait with update after the next sample
        await asyncio.sleep(gap+0.01)

      # update display with current values
      s = time.monotonic()
      self._update_views()
      if (self._new_sample or
          not self._app.key_events or
          self._cur_view == 1 or
          cur_view != self._cur_view):
        self._views[self._cur_view].show()
        cur_view = self._cur_view
        update_time = time.monotonic() - s
        #print("#_show_view: %f" % update_time)

      self._new_sample = False
      if not self._app.key_events:                      # auto toggle view
        self._cur_view = (self._cur_view+1) % len(self._views)


  # --- loop during ready-state   --------------------------------------------

  def run(self):
    """ main-loop during active-state """

    # reset state and query runtime-settings
    self._stop    = False
    self._int_fac = int_fac(self._settings.int_scale)
    self._dur_fac = dur_fac(self._settings.int_scale)
    self._int_t = self._settings.interval*self._int_fac # interval time in sec

    # reset views
    if self._app.display:
      self._cur_view = 0
      self._views[0].clear_values()
      self._views[0].show()

      d_scale = dur_scale(self._settings.int_scale)
      self._views[1].set_units([d_scale,d_scale])

      if self._settings.plots:
        # reset plots
        for i in range(self._dim):
          self._views[2+i].reset()

    gc.collect()
    asyncio.run(self._run())

  # --- loop during ready-state   --------------------------------------------

  async def _run(self):
    """ main-loop during active-state """

    key_task  = asyncio.create_task(self._check_key())
    view_task = asyncio.create_task(self._show_view())

    self._logger.open()
    self._logger.log_settings()
    m_data = DataAggregator(self._dim)
    c_view = 0

    # create digitalio objects for state-sampling
    if self._settings.pins_app:
      self._init_dios()
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

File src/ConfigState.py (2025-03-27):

# ----------------------------------------------------------------------------
# ConfigState.py: Handle config-state, i.e. display last results and enter
#                config or run-state depending on buttton input
#
# Author: Bernhard Bablok
# License: GPL3
#
# Website: https://github.com/bablokb/circuitpython-vameter
#
# ----------------------------------------------------------------------------

import time
from View import ConfigView
from Scales import *

class ConfigState:
  """ manage config-state """

  # --- constructor   --------------------------------------------------------

  def __init__(self,app):
    """ constructor """

    self._app   = app
    headings    = ['Int-Scale:','Interval:','Duration:','Update:']
    units       = ["",app.settings.int_scale,
                   dur_scale(app.settings.int_scale),'ms']
    self._attr  = ['int_scale','interval','duration','update']
    if app.settings.oversample > 0:
      headings.append('Oversample:')
      units.append('X')
      self._attr.append('oversample')
    try:
      config_data = app.data_provider.get_config_data()
      for heading, attribute, unit in config_data:
        headings.append(heading)
        units.append(unit)
        self._attr.append(attribute)
    except Exception as ex:
      # no config-views defined?!
      print(f"exception creating provider-specific config-views: {ex}")
      pass
    self._views = [ConfigView(app.display,app.settings.border,
                              headings[i],
                              units[i])
                   for i in range(len(headings))]
    self._int_view = self._views[1]
    self._dur_view = self._views[2]

  # --- update a setting   ----------------------------------------------------

  def _upd_value(self,nr):
    """ update value of current setting """

    value = str(getattr(self._app.settings,self._attr[nr]))
    while True:
      self._views[nr].set_value(value)
      self._views[nr].show()
      key = self._app.key_events.wait_for_key(self._app.key_events.KEYMAP_CONFIG)
      if key == 'NEXT':
        if nr == 0:
          setattr(self._app.settings,self._attr[nr],value)     # scale is a string
          self._int_view.set_unit(value)
          self._dur_view.set_unit(dur_scale(value))
        else:
          setattr(self._app.settings,self._attr[nr],int(value))
        return
      elif key == 'CLR':
        if nr == 0:
          value = 'ms'
        elif len(value) > 1:
          value = value[:-1]
        else:
          value = '0'
      elif value == '0':
        value = key
      elif nr == 0:
        index = min(int(key),len(INT_SCALES)) - 1
        value = list(INT_SCALES.items())[index][0]
      else:
        value = value+key

  # --- loop during config-state   --------------------------------------------

  def run(self):
    """ main-loop during config-state """

    if not self._app.display:
      return
    else:
      # loop over all settings
      for i in range(len(self._views)):
        self._upd_value(i)

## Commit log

2022-03-31 implement border-frame
2022-04-01 use board.SDA and board.SCL if available
2022-04-01 switch to pcf-fonts
2022-04-01 use board.DISPLAY if available
2022-04-04 add KeyEventProvider and fix i2c-in-use error
    [main.py]
2022-04-07 switch units for 'update' from s to ms
2022-04-07 ConfigView: switch type of value from float to string
2022-04-07 fixed links/title after rename of project
    [main.py]
2022-04-07 print duration at end of measurement
2022-04-07 catch error creating KeyEventProvider
    [main.py]
2022-04-08 log total number of samples and samples/s
2022-04-08 added i2c as parameter for constructor
2022-04-08 switch to INA219DataProvider
2022-04-15 add current value as label
2022-04-15 support output of supply-voltage
2022-04-15 don't start if current is below threshold
2022-04-15 support timeout while waiting for first sample
2022-04-19 added info about attaching power-source and load to the INA219
2022-04-19 don't show supply-voltage
2022-04-29 add support for ST7735R-based SPI-displays
2022-04-30 support additional attribute 'power'
2022-04-30 define default pins for Raspberry Pi
2022-05-05 don't sample power
2022-05-05 fix pin initialization
2022-05-06 added keypad
    [mpr121-keypad.scad]
2022-05-06 added *.stl
2022-05-06 added prototype keypad
    [mpr121-keypad.scad]
2022-05-07 add support for multiple lines of text on keys
    [mpr121-keypad.scad]
2022-05-07 reduced heigt of inset to 0.8
    [mpr121-keypad.scad]
2022-05-18 cleanup of unrelated wires
2022-05-20 add description of load-resistor
2022-05-23 add note about alternative sensors
2022-05-25 added pin-definitions for UART
2022-05-25 add spi to /boot/config.txt
2022-05-26 add support for QT Py ESP32-S2
2022-05-26 set I2C-frequency to 400k
2022-05-26 print msg without extra NL
2022-05-30 bugfix: use time.sleep() instead just sleep()
    [main.py]
2022-06-08 support exit-option for blinka-boards
2022-06-16 set current threshold to 0 and prevent negative current-values
2022-06-24 update views only after a new sample
2022-07-05 code cleanup: replaced 'tm_scale' with 'int_scale'
    [main.py]
2022-07-29 intial commit (Rev 1.0)
    [cp-vameter.kicad_pcb, cp-vameter.kicad_sch]
2022-07-29 added excludes for kicad
2022-08-01 removed code for inset
    [mpr121-keypad.scad]
2022-08-03 renamed variables
    [oled-128x64.scad]
2022-08-03 removed rim
    [oled-128x64.scad]
2022-08-09 refactored constants to dimensions.scad
    [mpr121-keypad.scad, oled-128x64.scad]
2022-08-10 changed thickness to base-thickness
    [mpr121-keypad.scad]
2022-08-10 removed snaps / set base=1.6
    [dimensions.scad]
2022-08-10 removed snaps
    [case.scad]
2022-08-11 removed snaps and optimized layout of oled/keypad
    [cover.scad]
2022-08-11 add oled/keypad as part of module cover
    [cover.scad]
2022-08-12 added w2-dimension
    [dimensions.scad]
2022-08-12 added walls
    [cover.scad]
2022-08-12 replaced tht-footprint with smd-footprint for JST-connector
    [cp-vameter.kicad_sch]
2022-08-17 switch to new sparkline implementation with dynamic x-pitch
2022-08-19 refactor configuration to def_config.py and board_config.py
2022-08-27 replaced tht-footprint with smd-footprint for JST-connector in pcb
    [cp-vameter.kicad_pcb]
2022-09-09 link to image of case
2022-09-09 add info about OpenSCAD-files for case
2023-10-27 fixed handling of reading from serial
    [cp-datalogger.py]
2024-02-22 added support for two new boards
2024-03-28 renamed directory due to changes in board-name
2024-12-19 print exception when user-specific config-file cannot be loaded
2025-01-05 added sample imports for DataProvider
2025-03-26 renamed ESP32Logger.py to UDPLogger.py
2025-03-26 replaced references to ESP32Logger with UDPLogger
    [UDPLogger.py, def_config.py, main.py]
2025-03-27 make I2C-address configurable
2025-03-28 fix syntax for CP 9.x
    [View.py]
2025-03-28 added board-definition for Seeed-Studio XIAO-RP2040
2025-03-28 bugfix: wrong initialization of aggregator
    [Data.py]
2025-03-28 bugfix: wrong implementation of adding GPIO-data
    [ActiveState.py]
2025-03-30 added missing libraries to installation
    [board_config.py]
2025-03-30 removed board-config for Pi Pico, since it is not board specific
2025-03-30 reduce to really board-specific configurations
2025-04-08 fixed format (once more) and changed program defaults
    [INA3221DataProvider.py]
2025-04-08 use default keys from board-module if not explicitely set
2025-06-13 print exceptions raised by import from user_config
2025-06-13 migrate to CP9 displayio modules (i2cdisplaybus, fourwire)
2026-03-03 bugfix: use shared-spi and pass cs as Pin
    [SDCardLogger.py]
2026-03-03 added mount-point
